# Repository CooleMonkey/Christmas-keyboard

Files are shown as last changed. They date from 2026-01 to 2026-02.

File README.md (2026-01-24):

# Christmas-keyboard
I will tell you something about my project. As the title already says, it's a christmas themed keyboard. I made the size 60/65% and I added a numpad to the left cause I hate it when the numpad to the right is in the way of my mouse.
So that's also the first reason why I made this project. The second reason is that I wanted to challenge myself during my holliday, instead of speningd hours and hours gaming and I definitely challenged myself.
The third reason was the fact that the best christmas themed project shipped before monday 5 januari 2026 would get a 3d-printer. That was a great motivation for me to start this project, cause I really want a 3d-printer.

During this project I had some struggles with the PCB and the 3d-case, but eventually I got everyhting the right way I wanted it, so I'm pretty happy when I'm looking back at the time I have spent into this project.
The case is made up of 5 parts so it can be printed in a 3d printer.
Schermafbeelding 2026-01-08 092757

## PCB
Schermafbeelding 2026-01-24 173924
Schermafbeelding 2026-01-24 173935

## Full 3D Model
Schermafbeelding 2026-01-08 092757

## 3D Case


## Bottom Case R
Schermafbeelding 2026-01-08 092441
Schermafbeelding 2026-01-08 092454

## Bottom Case L
Schermafbeelding 2026-01-08 092420
Schermafbeelding 2026-01-08 092430

## Top Case R
Schermafbeelding 2026-01-08 092405

## Top Case L1
Schermafbeelding 2026-01-08 092347

## Top Case L2
Schermafbeelding 2026-01-08 092356

## BOM


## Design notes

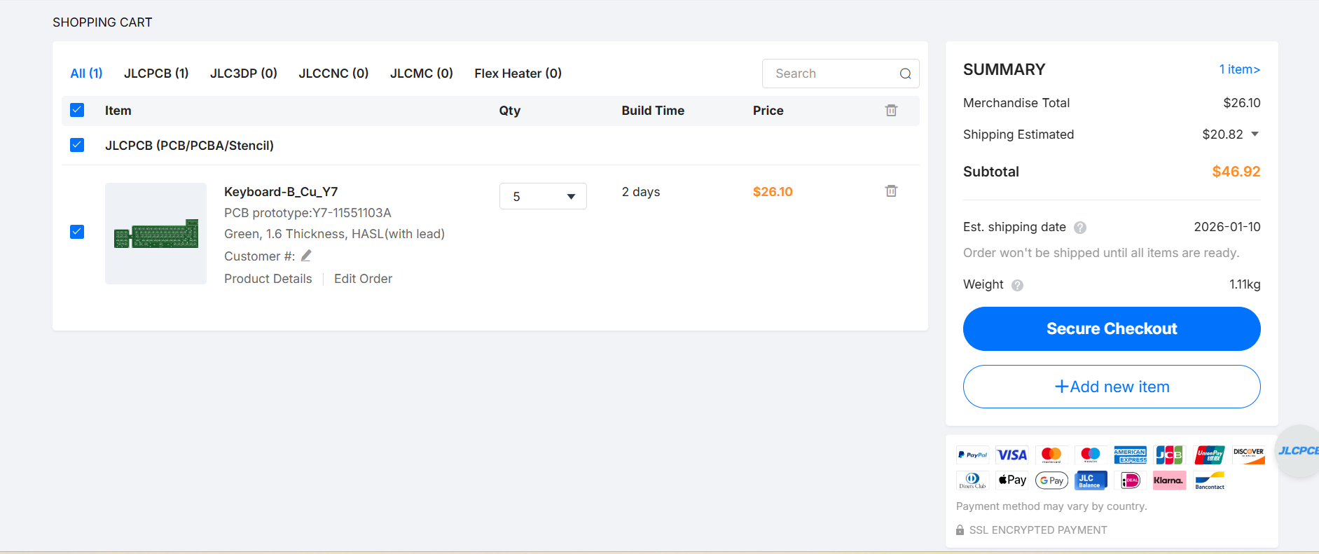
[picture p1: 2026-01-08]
Check-out_screenshots/Schermafbeelding 2026-01-08 085559.png

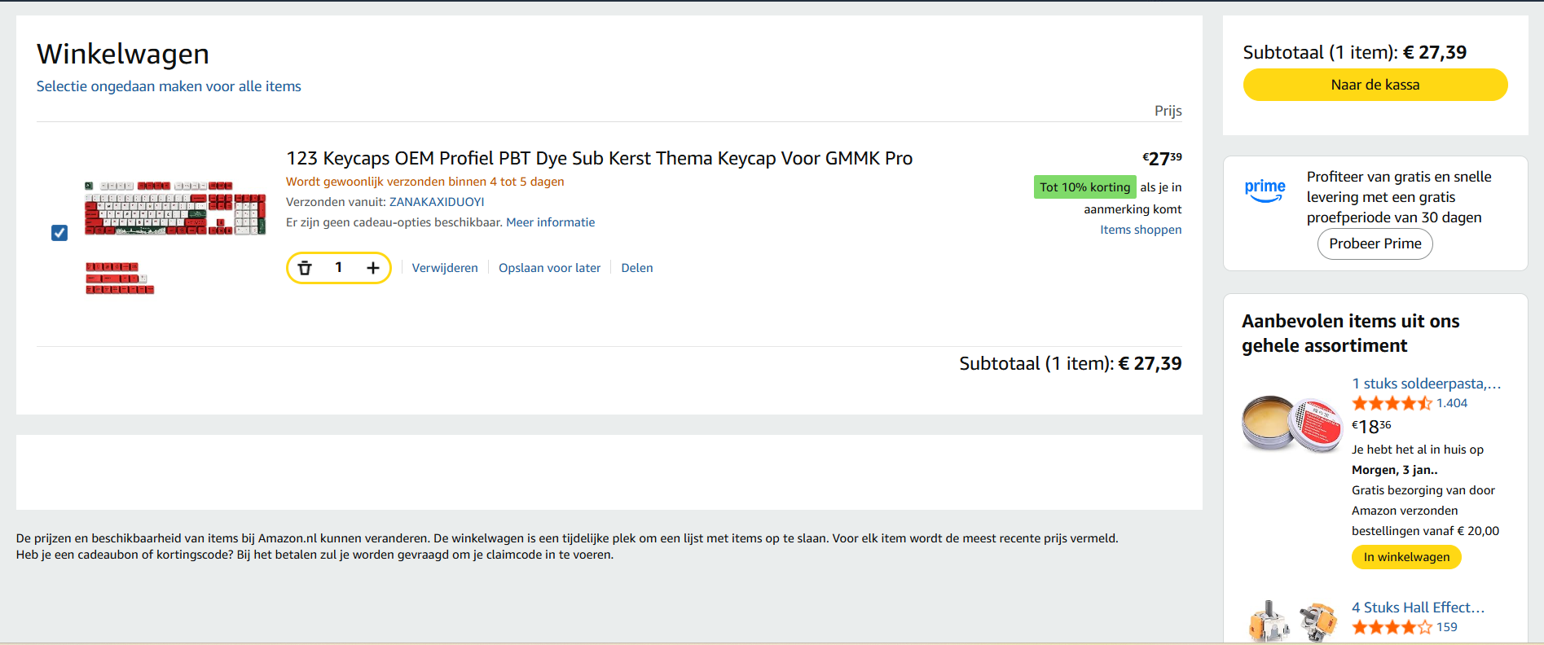
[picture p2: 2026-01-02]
Check-out_screenshots/Schermafbeelding 2026-01-02 114122.png

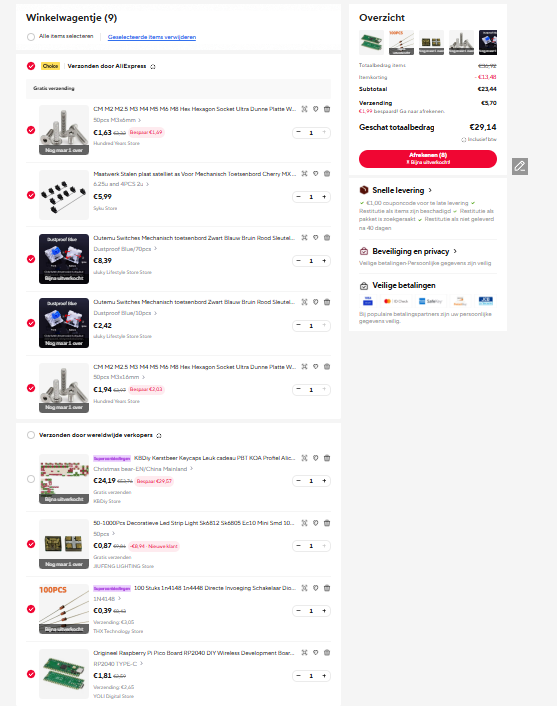
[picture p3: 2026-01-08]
Check-out_screenshots/Schermafbeelding 2026-01-08 090545.png

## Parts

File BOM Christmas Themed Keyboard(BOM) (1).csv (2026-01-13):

Product Name | Product Description | Product Unit Price ($) | Product Amount | Product Running Total ($) | Total price ($) | Product Link
M3 16mm screws (50pcs) | Screws (Note, the link does not go automaticly to what I have selected, but I have selected the M3 16mm screws) | 2,27 | 1 | 2,27 | 2,27 | https://nl.aliexpress.com/item/1005006674897468.html
M3 6mm screws (50pcs) | Screws to screw the PCB to the case. | 1,9 | 1 | 1,9 | 4,17 | https://nl.aliexpress.com/item/1005006674897468.html
123 Keycaps OEM Profiel PBT Dye Sub Kerst Thema Keycap Voor GMMK Pro | Keycaps | 32,11 | 1 | 32,11 | 36,28 | https://www.amazon.nl/Keycaps-Profiel-Kerst-Thema-Keycap/dp/B0FLD5J3ZZ
Outemu Switches Mechanisch toetsenbord Zwart Sleutelschakeleer voor CIY Sockets SMD 3pin Dunne pinnen Compatibel met MX Switch | Keyswitches 70pcs | 9,75 | 1 | 9,75 | 46,03 | https://nl.aliexpress.com/item/1005004285423123.html
Outemu Switches Mechanisch toetsenbord Zwart Sleutelschakeleer voor CIY Sockets SMD 3pin Dunne pinnen Compatibel met MX Switch | Keyswitches 10pcs | 2,88 | 1 | 2,88 | 48,91 | https://nl.aliexpress.com/item/1005004285423123.html
1N4181 Switching Diode Standard 75V 150MA Through Hole D0-35- 100 pieces | Diodes 100 pcs | 0,48 | 1 | 0,48 | 49,39 | https://www.aliexpress.com/item/1005007639751096.html
Origineel Raspberry Pi Pico Board Rp2040 DIY Wireless Development Board Type-C | Raspberry Pi Pico | 6,12 | 1 | 6,12 | 55,51 | https://nl.aliexpress.com/item/1005008450989559.html
3d printed case | 3d printed case | I will do this via printing legion |  |  | 55,51
stabilitsatoren MX Cherry switches | Stabilisatoren for the wide keys. | 5,98 | 1 | 5,98 | 61,49 | https://nl.aliexpress.com/item/1005001831944910.html
SK6812 mini LED's | SK6812 mini LED's (50pcs) | 1,01 | 1 | 1,01 | 62,5 | https://nl.aliexpress.com/item/1005005838997862.html
PCB | PCB | 46,92 | 1 | 46,92 | 109,42

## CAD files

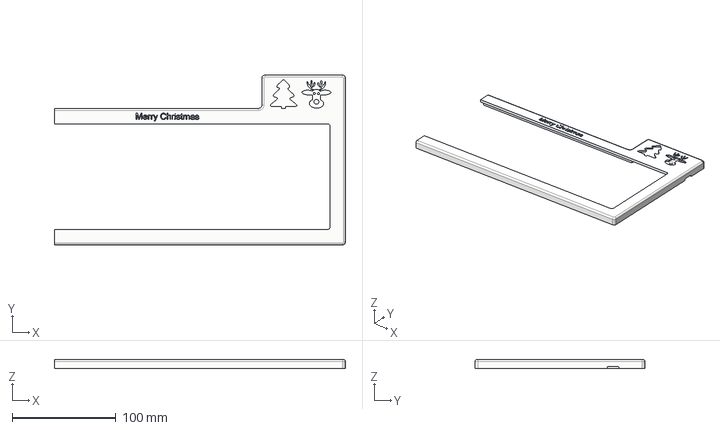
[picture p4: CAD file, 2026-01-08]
CAD/KB Top Case R.step
280.1 x 163.5 x 9.00 mm

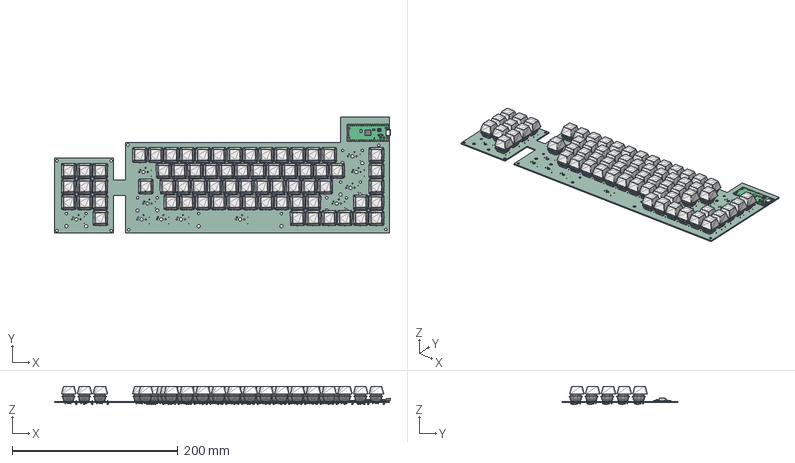
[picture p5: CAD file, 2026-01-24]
PCB/Keyboard.step
405.9 x 140.5 x 22.2 mm
RaspberryPi_Pico_Module_KiCad
MX1A-11NN--3DModel-STEP-510211 x 68
Simple-CherryMX-Keycap x 68
D_DO-35_SOD27_P7.62mm_Horizontal x 79
Keyboard_PCB

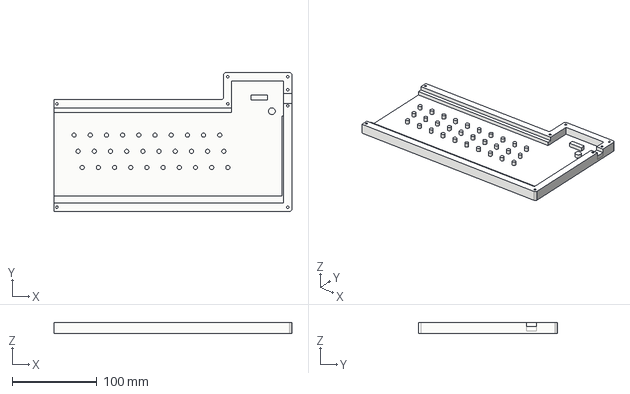
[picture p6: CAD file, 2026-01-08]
CAD/KB Bottom Case R.step
280.1 x 163.5 x 13.0 mm

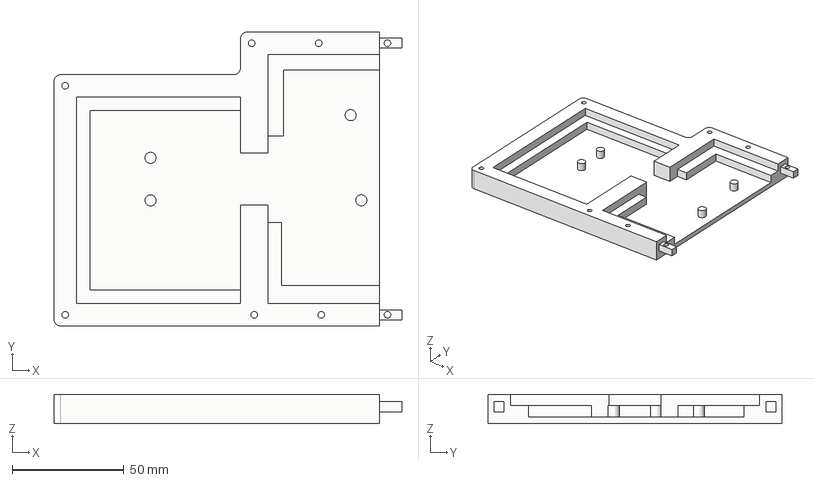
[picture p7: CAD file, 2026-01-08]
CAD/KB Bottom Case L.step
155.7 x 131.5 x 13.0 mm

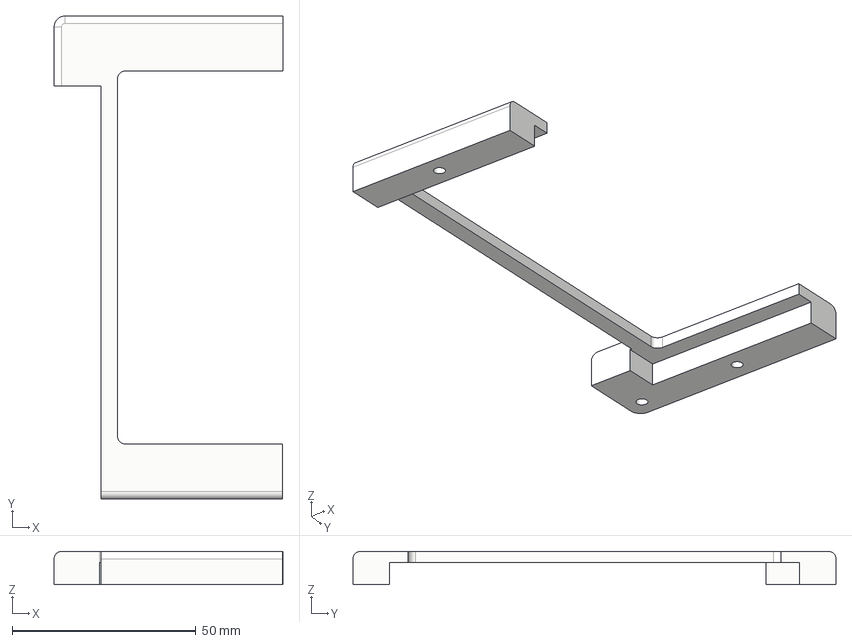
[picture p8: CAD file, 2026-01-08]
CAD/KB Top Case L2.step
62.3 x 131.5 x 9.00 mm

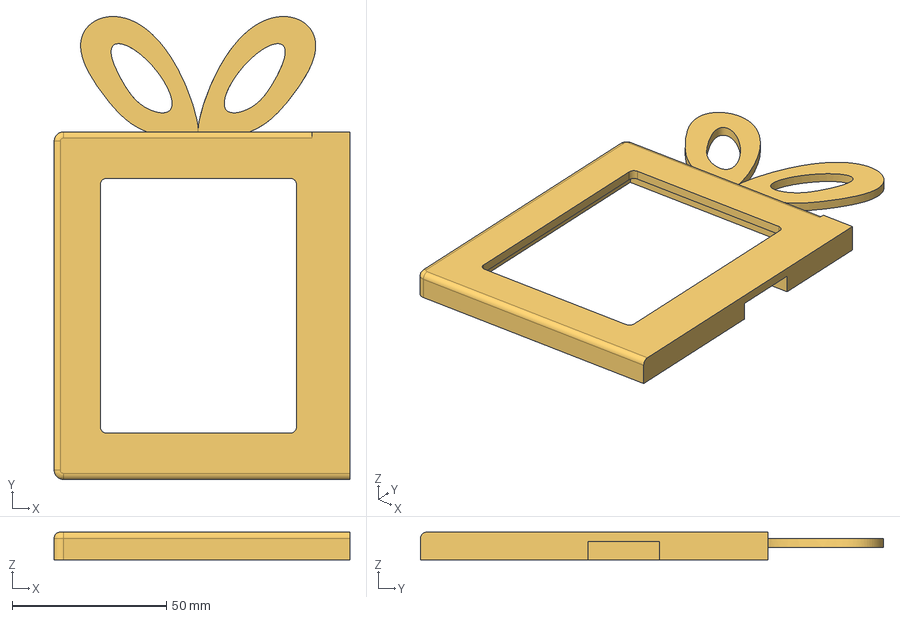
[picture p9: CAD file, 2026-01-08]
CAD/KB Top Case L1.step
95.7 x 149.9 x 9.00 mm

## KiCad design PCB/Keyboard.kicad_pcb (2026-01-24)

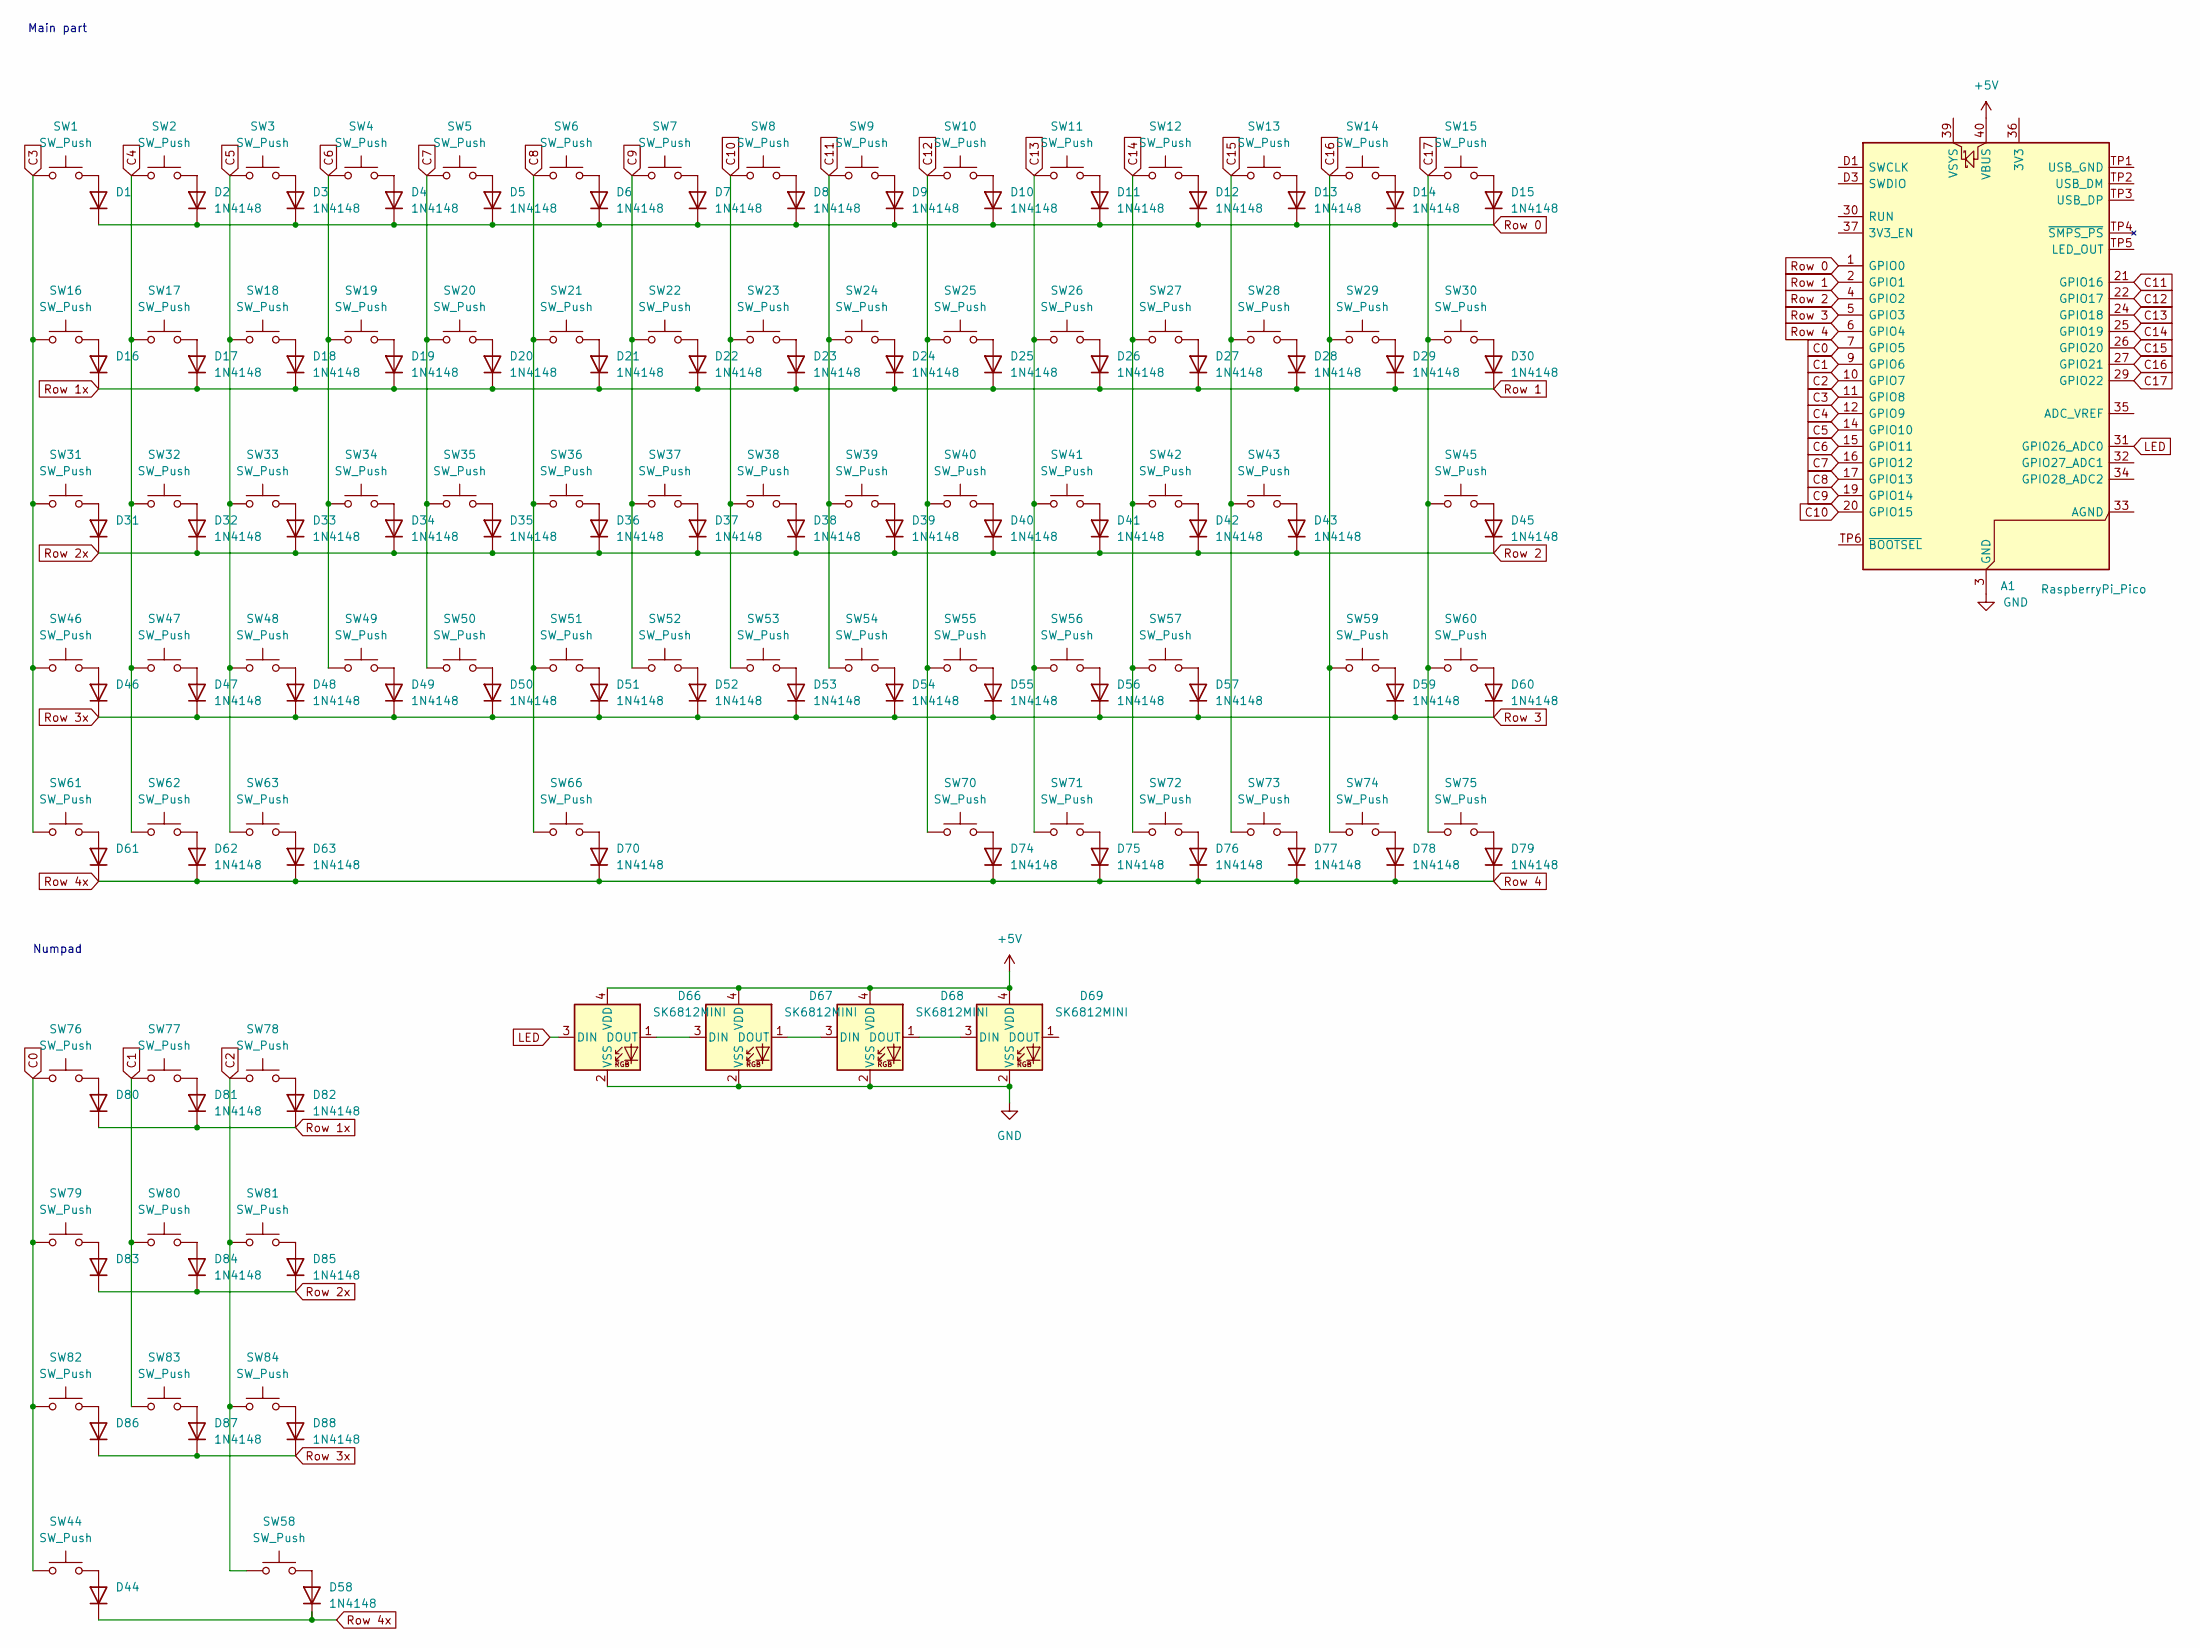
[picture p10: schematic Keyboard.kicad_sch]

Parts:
A1: RaspberryPi_Pico; RaspberryPi_Pico_SMD
D1, D2, D3, D4, D5, D6, D7, D8, D9, D10, D11, D12, D13, D14, D15, D16, D17, D18, D19, D20, D21, D22, D23, D24, D25, D26, D27, D28, D29, D30, D31, D32, D33, D34, D35, D36, D37, D38, D39, D40, D41, D42, D43, D44, D45, D46, D47, D48, D49, D50, D51, D52, D53, D54, D55, D56, D57, D58, D59, D60, D61, D62, D63, D70, D74, D75, D76, D77, D78, D79, D80, D81, D82, D83, D84, D85, D86, D87, D88: 1N4148; D_DO-35_SOD27_P7.62mm_Horizontal
D66, D67, D68, D69: SK6812MINI; LED_SK6812MINI_PLCC4_3.5x3.5mm_P1.75mm
SW1, SW2, SW3, SW4, SW5, SW6, SW7, SW8, SW9, SW10, SW11, SW12, SW13, SW15, SW17, SW18, SW19, SW20, SW21, SW22, SW23, SW24, SW25, SW26, SW27, SW28, SW30, SW31, SW32, SW33, SW34, SW35, SW36, SW37, SW38, SW39, SW40, SW41, SW42, SW45, SW47, SW48, SW49, SW50, SW51, SW52, SW53, SW54, SW55, SW56, SW58, SW59, SW60, SW70, SW71, SW72, SW73, SW74, SW75, SW76, SW77, SW78, SW79, SW80, SW81, SW82, SW83, SW84: SW_Push; SW_Cherry_MX_1.00u_PCB
SW14, SW44, SW46, SW57: SW_Push; SW_Cherry_MX_2.00u_PCB
SW16, SW29: SW_Push; SW_Cherry_MX_1.50u_PCB
SW43: SW_Push; SW_Cherry_MX_2.25u_PCB
SW61, SW62, SW63: SW_Push; SW_Cherry_MX_1.25u_PCB
SW66: SW_Push; SW_Cherry_MX_6.25u_PCB

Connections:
+5V: A1.40 (VBUS), D66.4 (VDD), D67.4 (VDD), D68.4 (VDD), D69.4 (VDD)
C0: A1.7 (GPIO5), SW44.1, SW76.1, SW79.1, SW82.1
C1: A1.9 (GPIO6), SW77.1, SW80.1, SW83.1
C2: A1.10 (GPIO7), SW58.1, SW78.1, SW81.1, SW84.1
C3: A1.11 (GPIO8), SW1.1, SW16.1, SW31.1, SW46.1, SW61.1
C4: A1.12 (GPIO9), SW2.1, SW17.1, SW32.1, SW47.1, SW62.1
C5: A1.14 (GPIO10), SW3.1, SW18.1, SW33.1, SW48.1, SW63.1
C6: A1.15 (GPIO11), SW4.1, SW19.1, SW34.1, SW49.1
C7: A1.16 (GPIO12), SW5.1, SW20.1, SW35.1, SW50.1
C8: A1.17 (GPIO13), SW6.1, SW21.1, SW36.1, SW51.1, SW66.1
C9: A1.19 (GPIO14), SW7.1, SW22.1, SW37.1, SW52.1
C10: A1.20 (GPIO15), SW8.1, SW23.1, SW38.1, SW53.1
C11: A1.21 (GPIO16), SW9.1, SW24.1, SW39.1, SW54.1
C12: A1.22 (GPIO17), SW10.1, SW25.1, SW40.1, SW55.1, SW70.1
C13: A1.24 (GPIO18), SW11.1, SW26.1, SW41.1, SW56.1, SW71.1
C14: A1.25 (GPIO19), SW12.1, SW27.1, SW42.1, SW57.1, SW72.1
C15: A1.26 (GPIO20), SW13.1, SW28.1, SW43.1, SW73.1
C16: A1.27 (GPIO21), SW14.1, SW29.1, SW59.1, SW74.1
C17: A1.29 (GPIO22), SW15.1, SW30.1, SW45.1, SW60.1, SW75.1
GND: A1.3 (GND), A1.8 (GND), A1.13 (GND), A1.18 (GND), A1.23 (GND), A1.28 (GND), A1.38 (GND), A1.D2 (GND), D66.2 (VSS), D67.2 (VSS), D68.2 (VSS), D69.2 (VSS)
LED: A1.31 (GPIO26_ADC0), D66.3 (DIN)
unnamed: D1.2 (A), SW1.2
unnamed: D2.2 (A), SW2.2
unnamed: D3.2 (A), SW3.2
unnamed: D4.2 (A), SW4.2
unnamed: D5.2 (A), SW5.2
unnamed: D6.2 (A), SW6.2
unnamed: D7.2 (A), SW7.2
unnamed: D8.2 (A), SW8.2
unnamed: D9.2 (A), SW9.2
unnamed: D10.2 (A), SW10.2
unnamed: D11.2 (A), SW11.2
unnamed: D12.2 (A), SW12.2
unnamed: D13.2 (A), SW13.2
unnamed: D14.2 (A), SW14.2
unnamed: D15.2 (A), SW15.2
unnamed: D16.2 (A), SW16.2
unnamed: D17.2 (A), SW17.2
unnamed: D18.2 (A), SW18.2
unnamed: D19.2 (A), SW19.2
unnamed: D20.2 (A), SW20.2
unnamed: D21.2 (A), SW21.2
unnamed: D22.2 (A), SW22.2
unnamed: D23.2 (A), SW23.2
unnamed: D24.2 (A), SW24.2
unnamed: D25.2 (A), SW25.2
unnamed: D26.2 (A), SW26.2
unnamed: D27.2 (A), SW27.2
unnamed: D28.2 (A), SW28.2
unnamed: D29.2 (A), SW29.2
unnamed: D30.2 (A), SW30.2
unnamed: D31.2 (A), SW31.2
unnamed: D32.2 (A), SW32.2
unnamed: D33.2 (A), SW33.2
unnamed: D34.2 (A), SW34.2
unnamed: D35.2 (A), SW35.2
unnamed: D36.2 (A), SW36.2
unnamed: D37.2 (A), SW37.2
unnamed: D38.2 (A), SW38.2
unnamed: D39.2 (A), SW39.2
unnamed: D40.2 (A), SW40.2
unnamed: D41.2 (A), SW41.2
unnamed: D42.2 (A), SW42.2
unnamed: D43.2 (A), SW43.2
unnamed: D44.2 (A), SW44.2
unnamed: D45.2 (A), SW45.2
unnamed: D46.2 (A), SW46.2
unnamed: D47.2 (A), SW47.2
unnamed: D48.2 (A), SW48.2
unnamed: D49.2 (A), SW49.2
unnamed: D50.2 (A), SW50.2
unnamed: D51.2 (A), SW51.2
unnamed: D52.2 (A), SW52.2
unnamed: D53.2 (A), SW53.2
unnamed: D54.2 (A), SW54.2
unnamed: D55.2 (A), SW55.2
unnamed: D56.2 (A), SW56.2
unnamed: D57.2 (A), SW57.2
unnamed: D58.2 (A), SW58.2
unnamed: D59.2 (A), SW59.2
unnamed: D60.2 (A), SW60.2
unnamed: D61.2 (A), SW61.2
unnamed: D62.2 (A), SW62.2
unnamed: D63.2 (A), SW63.2
unnamed: D66.1 (DOUT), D67.3 (DIN)
unnamed: D67.1 (DOUT), D68.3 (DIN)
unnamed: D68.1 (DOUT), D69.3 (DIN)
unnamed: D70.2 (A), SW66.2
unnamed: D74.2 (A), SW70.2
unnamed: D75.2 (A), SW71.2
unnamed: D76.2 (A), SW72.2
unnamed: D77.2 (A), SW73.2
unnamed: D78.2 (A), SW74.2
unnamed: D79.2 (A), SW75.2
unnamed: D80.2 (A), SW76.2
unnamed: D81.2 (A), SW77.2
unnamed: D82.2 (A), SW78.2
unnamed: D83.2 (A), SW79.2
unnamed: D84.2 (A), SW80.2
unnamed: D85.2 (A), SW81.2
unnamed: D86.2 (A), SW82.2
unnamed: D87.2 (A), SW83.2
unnamed: D88.2 (A), SW84.2
Row 0: A1.1 (GPIO0), D1.1 (K), D2.1 (K), D3.1 (K), D4.1 (K), D5.1 (K), D6.1 (K), D7.1 (K), D8.1 (K), D9.1 (K), D10.1 (K), D11.1 (K), D12.1 (K), D13.1 (K), D14.1 (K), D15.1 (K)
Row 1: A1.2 (GPIO1), D16.1 (K), D17.1 (K), D18.1 (K), D19.1 (K), D20.1 (K), D21.1 (K), D22.1 (K), D23.1 (K), D24.1 (K), D25.1 (K), D26.1 (K), D27.1 (K), D28.1 (K), D29.1 (K), D30.1 (K), D80.1 (K), D81.1 (K), D82.1 (K)
Row 2: A1.4 (GPIO2), D31.1 (K), D32.1 (K), D33.1 (K), D34.1 (K), D35.1 (K), D36.1 (K), D37.1 (K), D38.1 (K), D39.1 (K), D40.1 (K), D41.1 (K), D42.1 (K), D43.1 (K), D45.1 (K), D83.1 (K), D84.1 (K), D85.1 (K)
Row 3: A1.5 (GPIO3), D46.1 (K), D47.1 (K), D48.1 (K), D49.1 (K), D50.1 (K), D51.1 (K), D52.1 (K), D53.1 (K), D54.1 (K), D55.1 (K), D56.1 (K), D57.1 (K), D59.1 (K), D60.1 (K), D86.1 (K), D87.1 (K), D88.1 (K)
Row 4: A1.6 (GPIO4), D44.1 (K), D58.1 (K), D61.1 (K), D62.1 (K), D63.1 (K), D70.1 (K), D74.1 (K), D75.1 (K), D76.1 (K), D77.1 (K), D78.1 (K), D79.1 (K)

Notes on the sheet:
Numpad
Main part

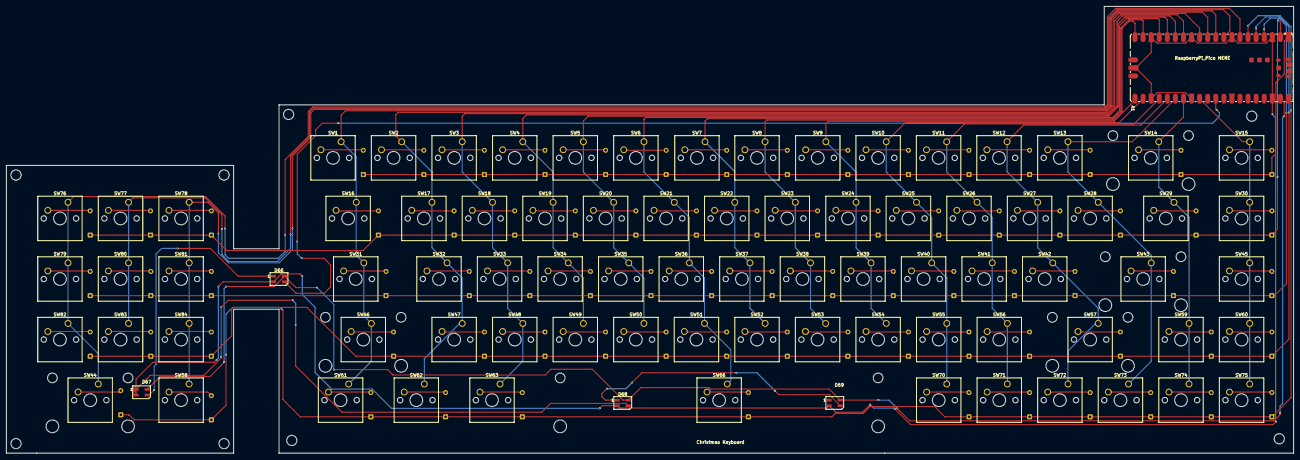
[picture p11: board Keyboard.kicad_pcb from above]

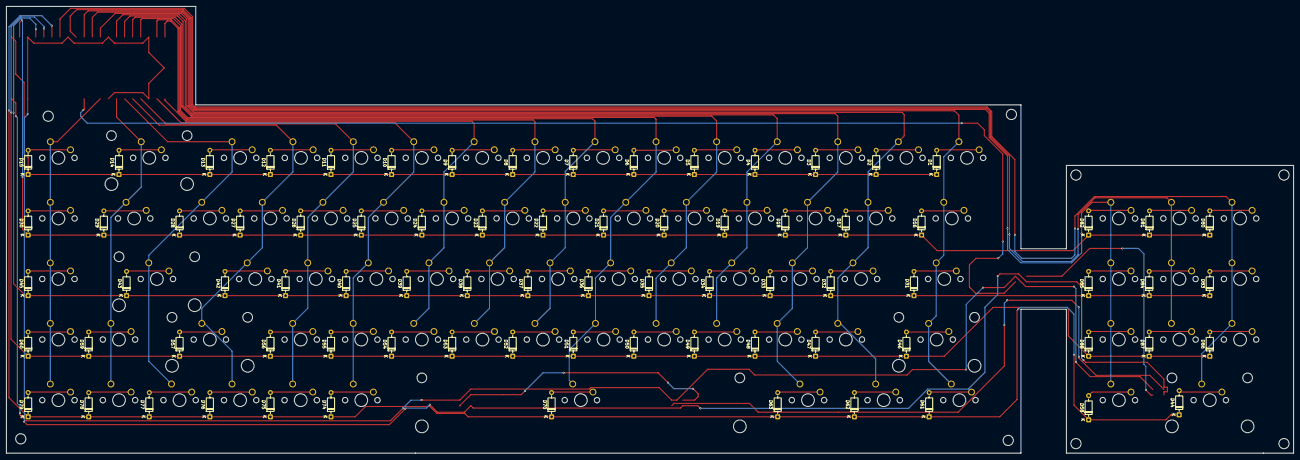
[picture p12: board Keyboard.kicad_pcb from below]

Board: 2 copper layers, 404.8 x 140.5 mm, 163 parts (79 on the bottom side), 108 nets.

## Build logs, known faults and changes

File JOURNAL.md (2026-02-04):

# 30-12-2025 18:15
I started looking for a layout for the keyboard and found this. The base will be this, but I will add a numpad to the left cause I wanna control my mouse with my right hand.
So this way I can use my mouse and numpad at the same time and my numpad isn't in the way of my mouse.
keyboard-layout-custom60-e1695896529533

# 30-12-2025 18:45
Just finished the first part of my layout, but still working on it. Cause it takes some time and I wanna add lights. I used a matrix to connect everything, cause that way I need less pins on the Raspberry Pi. Since I already did this for my hackpad it wasn't that hard to do it for my keyboard. I also tried to connect everything in a logical way. So that when I start coding and connecting all the wires it will be a bit easier. I'm also really glad that I first made a hackpad cause now I understand everything pretty well.


# 30-12-2025 19:15
I added some lights and found out that I had forgotten a row so and then I wired everything up. I used the sk6812 mini's, cause those are the only ones where I know how to wire them up correctly, cause they were also used in the hackpad tutorial.
Note: Found out later on, that the lights weren't connected right.


# 30-12-2025 21:15
The keyboard is slowly coming to life. Just started with wiring everything up.
I started this project today at 18:00 and around 3 hours of work later I arrived at the wiring, but still a lot has to be done. Btw I took a 20 minute break to eat from 19:40 to 20:00.
I think I'm going to run all the column wires through the top part cause there is a lot of space there and the rows can go through the right part to the Raspberry Pi.


# 30-12-2025 21:50
Finally done with the wiring. Spend about 3.5 hours today. My plan did work great. All wires are routed pretty neat and everything looks clear.
I'm also pretty surprised that I didn't have to do much wiring on the back of the PCB, but that probably indicates that I did everything pretty effiecently.


# 31-12-2025 13:30
Started thinking about the 3d case design. Cause not every 3d printer can support a 40 cm wide keyboard. So I need to break it up into some parts.
My plan is to break the case up into 2 sides. Those sides will overlap at a specific point and there will be a hole in that overlap, so that I can screw them together.

# 31-12-2025 14:30
Still working on the right bottom part of the case. The hardest struggle was getting all the dimensions right.


# 31-12-2025 15:30
Right bottom case is almost done. Just needs some finishing touches and screw holes for the pcb. I also still need to think about how I'm gonna make sure the pcb won't move. Option 1 is screwing, but I don't really like that, but that is probably the best option I have.


# 31-12-2025 18:30
Don't ask me how, but I just spend a whole hour trying to get the right 3d model for the keyswitches in KiCad.
Total hours spend is now 6.5 and I'm estimating this will be at least 10 when I'm done with everything.
I'm planning to do the bottom left case tomorrow and then I will check the 3d case with the 3d pcb to check if all proportions are right.
If all the proportions are right, then I will proceed with the upper part of the case.


# 1-1-2026 11:00
It's the first day of 2026 and I made some improvements to the pcb board and right bottom case in half an hour. On the right bottom case I rounded the corners and made the hole for the usb end of the raspberry pi pico a bit larger. On the PCB I made the first 2 holes to screw to pcb to the case and I moved some wires more to the inside to make sure they won't be damaged by the screws.

# 1-1-2026 13:00
Time is going so fast when I'm having fun. Just put another hour into this project. The bottom left case is almost done. When that's completely done I will make the last screw holes in the PCB and start working on the Upper part of the case.



# 1-1-2026 15:00
Another hour has gone by and the Upper right case is done. It's very entertaining to see your vision slowly coming to life.



# 1-1-2026 18:30
After 2 hours the full upper case is done. In my opion it looks really good. The only thing left for me to do in CAD is color the 5 different parts. Tonight or tomorrow I will write the firmware for the keyboard.


# 1-1-2026 21:30
It took my a stunning 1,5 hours and some help of chatgpt to write the code. I thought I had found a great youtube video with explanation, but when it was almost at the end I found out I couldn't use that way, so than I had to start all over again. But anyway, my code should work now.


# 1-1-2026 23:00
Just made some small cute cuts in the top part of the case.


# 2-1-2026 11:00
I've added BOM and all the files. Everything if finally done. I'm pretty proud of this project.
Schermafbeelding 2026-01-02 100633

# 8-1-2026 9:00
My keyboard got reviewed last night and I had to change some things. The first thing is that some of the PCB wires didn't look good and that I should use 45 degree angels instead of 90 degree angles. So I just fixed the PCB. I also changed the BOM a little bit, cause I forgot to add the screws to mount the PCB to the case. I won't maken screw holes in the case to mount to PCB for the case cause I can do that later on with some special tools, so that way I can make sure the PCB fits in it's place.
BTW, this cost me 30 minutes.


# 8-1-2026 9:30
After another 30 minutes of working everything should now be fixed. I made it so that I can screw the M3 16mm screws from the bottom and that there is enough room for the head of the screw to 'dissapear in the case'.
Schermafbeelding 2026-01-08 092430

# 24-1-2026 14:00
Stupid me forgot to connect the LED's the right way so I had to fix that, but that meant that I also had to reupload the files to GitHub, etc. So it took some time. I'm hoping that this is the last change I need to make so that I can soon order everything and build it in my vacation that starts in 3 weeks.

# 24-1-2026 17:30
After I got some small feedback about the pin I was using for the LED's I switched it to GPIO26. This should be easier to solder. So that makes my life a little bit easier.
Schermafbeelding 2026-01-24 173924
Schermafbeelding 2026-01-24 173935

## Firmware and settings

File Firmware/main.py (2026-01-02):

import board

from kmk.kmk_keyboard import KMKKeyboard
from kmk.scanners import MatrixScanner
from kmk.keys import KC
from kmk.extensions.rgb import RGB


# Maak keyboard aan
keyboard = KMKKeyboard()

# Definieer rows en columns
ROW_PINS = (board.GP0, board.GP1, board.GP2, board.GP3, board.GP4)
COL_PINS = (board.GP5, board.GP6, board.GP7, board.GP8, board.GP9, board.GP10, board.GP11, board.GP12, board.GP13, board.GP14, board.GP15, board.GP16, board.GP17, board.GP18, board.GP19, board.GP20, board.GP21, board.GP22)

# Matrix scanner instellen
keyboard.matrix = MatrixScanner(
    row_pins=ROW_PINS,
    col_pins=COL_PINS,
    columns_to_anodes=False,  # True als je diodes andersom zitten
)

# Keymap (row-major order!)
keyboard.keymap = [
    [
        # Row 0
        KC.GRAVE, KC.1, KC.2, KC.3, KC.4, KC.5, KC.6, KC.7, KC.8, KC.9, KC.0, KC.MINUS, KC.EQUAL, KC.BSPACE, KC.DELETE

        # Row 1
        KC.KP_7, KC.KP_8, KC.KP_9, KC.TAB, KC.Q, KC.W, KC.E, KC.R, KC.T, KC.Y, KC.U, KC.I, KC.O, KC.P, KC.LBRACKET, KC.RBRACKET, KC.BSLASH, KC.PGUP

        # Row 2
        KC.KP_4, KC.KP_5, KC.KP_6, KC.LOCKING_CAPS, KC.A, KC.S, KC.D, KC.F, KC.G, KC.H, KC.J, KC.K, KC.L, KC.SCOLON, KC.QUOTE, KC.ENTER, KC.NO, KC.PGDOWN

        # Row 3
        KC.KP_1, KC.KP_2, KC.KP_3, KC.LSHIFT, KC.Z, KC.X, KC.C, KC.V, KC.B, KC.N, KC.M, KC.COMMA, KC.DOT, KC.SLASH, KC.RSHIFT, KC.NO, KC.UP, KC.EncodingWarning

        # Row 4
        KC.KP_0, KC.NO, KC.KP_DOT, KC.LCTRL, KC.LGUI, KC.LALT, KC.NO, KC.NO, KC.SPACE, KC.NO, KC.NO, KC.NO, KC.RALT, KC.RGUI, KC.RCTRL, KC.LEFT, KC.DOWN, KC.RIGHT
    ]
]

rgb = RGB(
    pixel_pin=board.GP28,  # DIN van eerste SK6812
    num_pixels=4,          # 4 LEDs
    hue_default=170,       # blauw/paars
    sat_default=255,
    val_default=80,        # veilige helderheid
)

keyboard.extensions.append(rgb)

# Startkleur groen
current_color = [0, 255, 0]

def set_rgb_color(color):
    global current_color
    for i in range(rgb.num_pixels):
        rgb.pixels[i] = color
    rgb.show()
    current_color = list(color)

def fade_to_color(target_color, steps=20, delay=0.01):
    global current_color
    # Bereken stapgroottes voor R, G, B
    step = [(target_color[i] - current_color[i]) / steps for i in range(3)]
    for s in range(steps):
        new_color = [int(current_color[i] + step[i]*(s+1)) for i in range(3)]
        set_rgb_color(new_color)
        time.sleep(delay)

@keyboard.on_press
def on_key_press(key):
    # Fade naar rood
    fade_to_color([255, 0, 0])

@keyboard.on_release
def on_key_release(key):
    # Fade terug naar groen
    fade_to_color([0, 255, 0])


# Start KMK
if __name__ == '__main__':
    keyboard.go()

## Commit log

2025-12-31 Add entry about 3D case design considerations
    Document thoughts on 3D case design for keyboard.
2025-12-31 Document progress on right bottom case assembly
    Added an entry about the progress on the right bottom case, including challenges and considerations for securing the PCB.
2026-01-01 Add journal entry for January 1, 2026
    Added journal entry for January 1, 2026, detailing improvements made to the PCB board and right bottom case.
2026-01-01 Document progress on Upper right case in JOURNAL.md
    Added a new entry documenting progress on the Upper right case.
2026-01-01 Document progress on upper case and firmware plans
    Added entry for completion of upper case and firmware plans.
2026-01-02 Update README with PCB and 3D model images
    Added images for PCB and full 3D model in README.
2026-01-02 Add BOM section with image to README
2026-01-02 Add new image to BOM section
    Added a new image to the BOM section of the README.
2026-01-02 Add new image to BOM section in README
    Added a new image for the BOM section in README.
2026-01-02 Add new BOM image to README
2026-01-13 Update BOM with new product entries
    Added new product entries and updated existing ones in the BOM.
    [BOM Christmas Themed Keyboard(BOM).csv]
2026-01-13 Update BOM Christmas Themed Keyboard(BOM).csv
    [BOM Christmas Themed Keyboard(BOM).csv]
2026-01-13 Revise BOM for Christmas themed keyboard
    Updated product details and prices in the BOM for the Christmas themed keyboard.
    [BOM Christmas Themed Keyboard(BOM) (1).csv]
2026-01-24 Add new images to PCB section in README
2026-01-24 Update JOURNAL with recent progress and fixes
    Added a new entry about fixing LED connections and reuploading files.
2026-01-24 Add entry about LED pin change and images
    Updated the journal with feedback on LED pin usage and added images.
2026-02-04 Enhance journal entries with project details
    Expanded journal entries with additional details about the keyboard layout project, including wiring and lighting updates.
